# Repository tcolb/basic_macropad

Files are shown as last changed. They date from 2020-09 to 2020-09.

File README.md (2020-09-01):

# basic_macropad
 
A small macropad with programmable keys, hot-swap MX connectors, LEDS, 3D printed case, and volume encoder

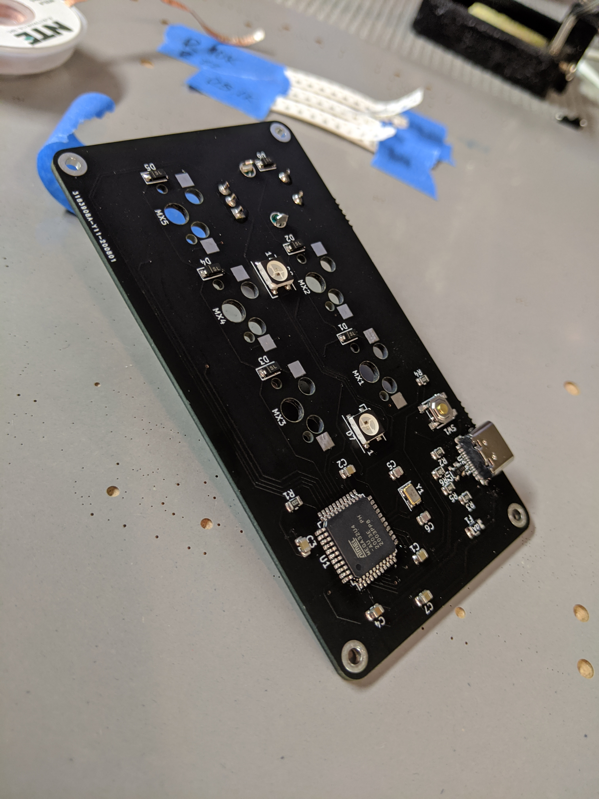
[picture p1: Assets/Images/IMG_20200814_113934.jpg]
PCB

CASE

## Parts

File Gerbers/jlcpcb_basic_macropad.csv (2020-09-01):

Comment | Designator | Footprint | LCSC
0.1uF | C1,C2,C3 | Capacitor_SMD:C_0805_2012Metric | C49678
10uF | C4 | Capacitor_SMD:C_0805_2012Metric | C15850
22pF | C5,C6 | Capacitor_SMD:C_0805_2012Metric | C1804
1uF | C7 | Capacitor_SMD:C_0805_2012Metric | C28323
SOD-123 | D1,D2,D3,D4,D5,D6 | Diode_SMD:D_SOD-123 | C8598
WS2812B | D7,D8 | LED_SMD:LED_WS2812B_PLCC4_5.0x5.0mm_P3.2mm | C114586
500mA | F1 | Fuse:Fuse_1206_3216Metric | C206993
MountingHole_Pad | H1,H2,H3,H4 | MountingHole:MountingHole_2.2mm_M2_Pad
MX-NoLED | MX1,MX2,MX3,MX4,MX5 | MX_Only:MXOnly-1U-Hotswap
10k | R1,R4 | Resistor_SMD:R_0805_2012Metric | C17414
5.1k | R2,R3 | Resistor_SMD:R_0805_2012Metric | C27834
22 | R5,R6 | Resistor_SMD:R_0805_2012Metric | C17561
SW_Push | SW1 | random-keyboard-parts:SKQG-1155865 | C318884
Rotary_Encoder_Switch | SW2 | Rotary_Encoder:RotaryEncoder_Alps_EC11E-Switch_Vertical_H20mm_CircularMountingHoles
ATmega32U4-AU | U1 | Package_QFP:TQFP-44_10x10mm_P0.8mm | C44854
PRTR5V0U2X | U2 | random-keyboard-parts:SOT143B
HRO-TYPE-C-31-M-12 | USB1 | Type-C:HRO-TYPE-C-31-M-12-Assembly
16MHz | Y1 | Crystal:Crystal_SMD_3225-4Pin_3.2x2.5mm | C13738

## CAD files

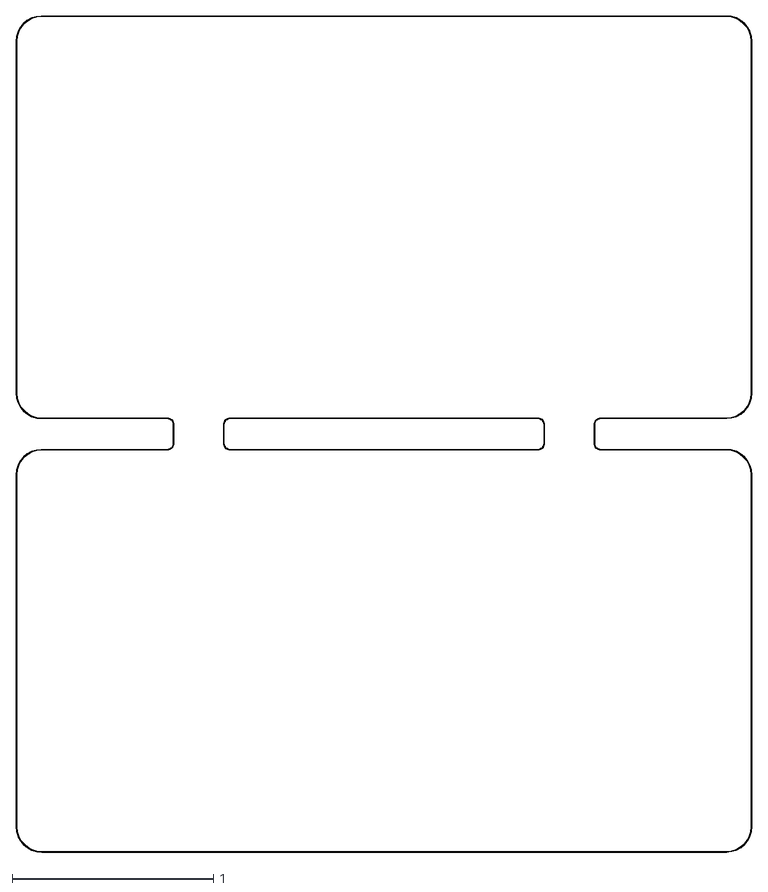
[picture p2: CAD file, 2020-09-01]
Assets/basic_macropad-Edge_Cuts.dxf
3.66 x 4.16

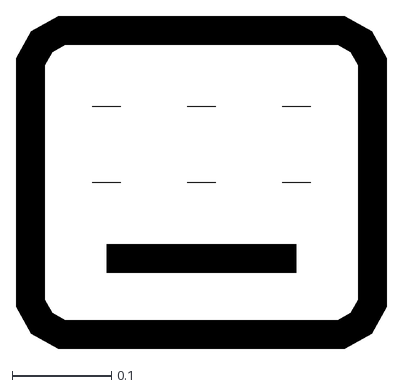
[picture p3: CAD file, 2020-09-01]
Assets/keyboard.dxf
0.372 x 0.334

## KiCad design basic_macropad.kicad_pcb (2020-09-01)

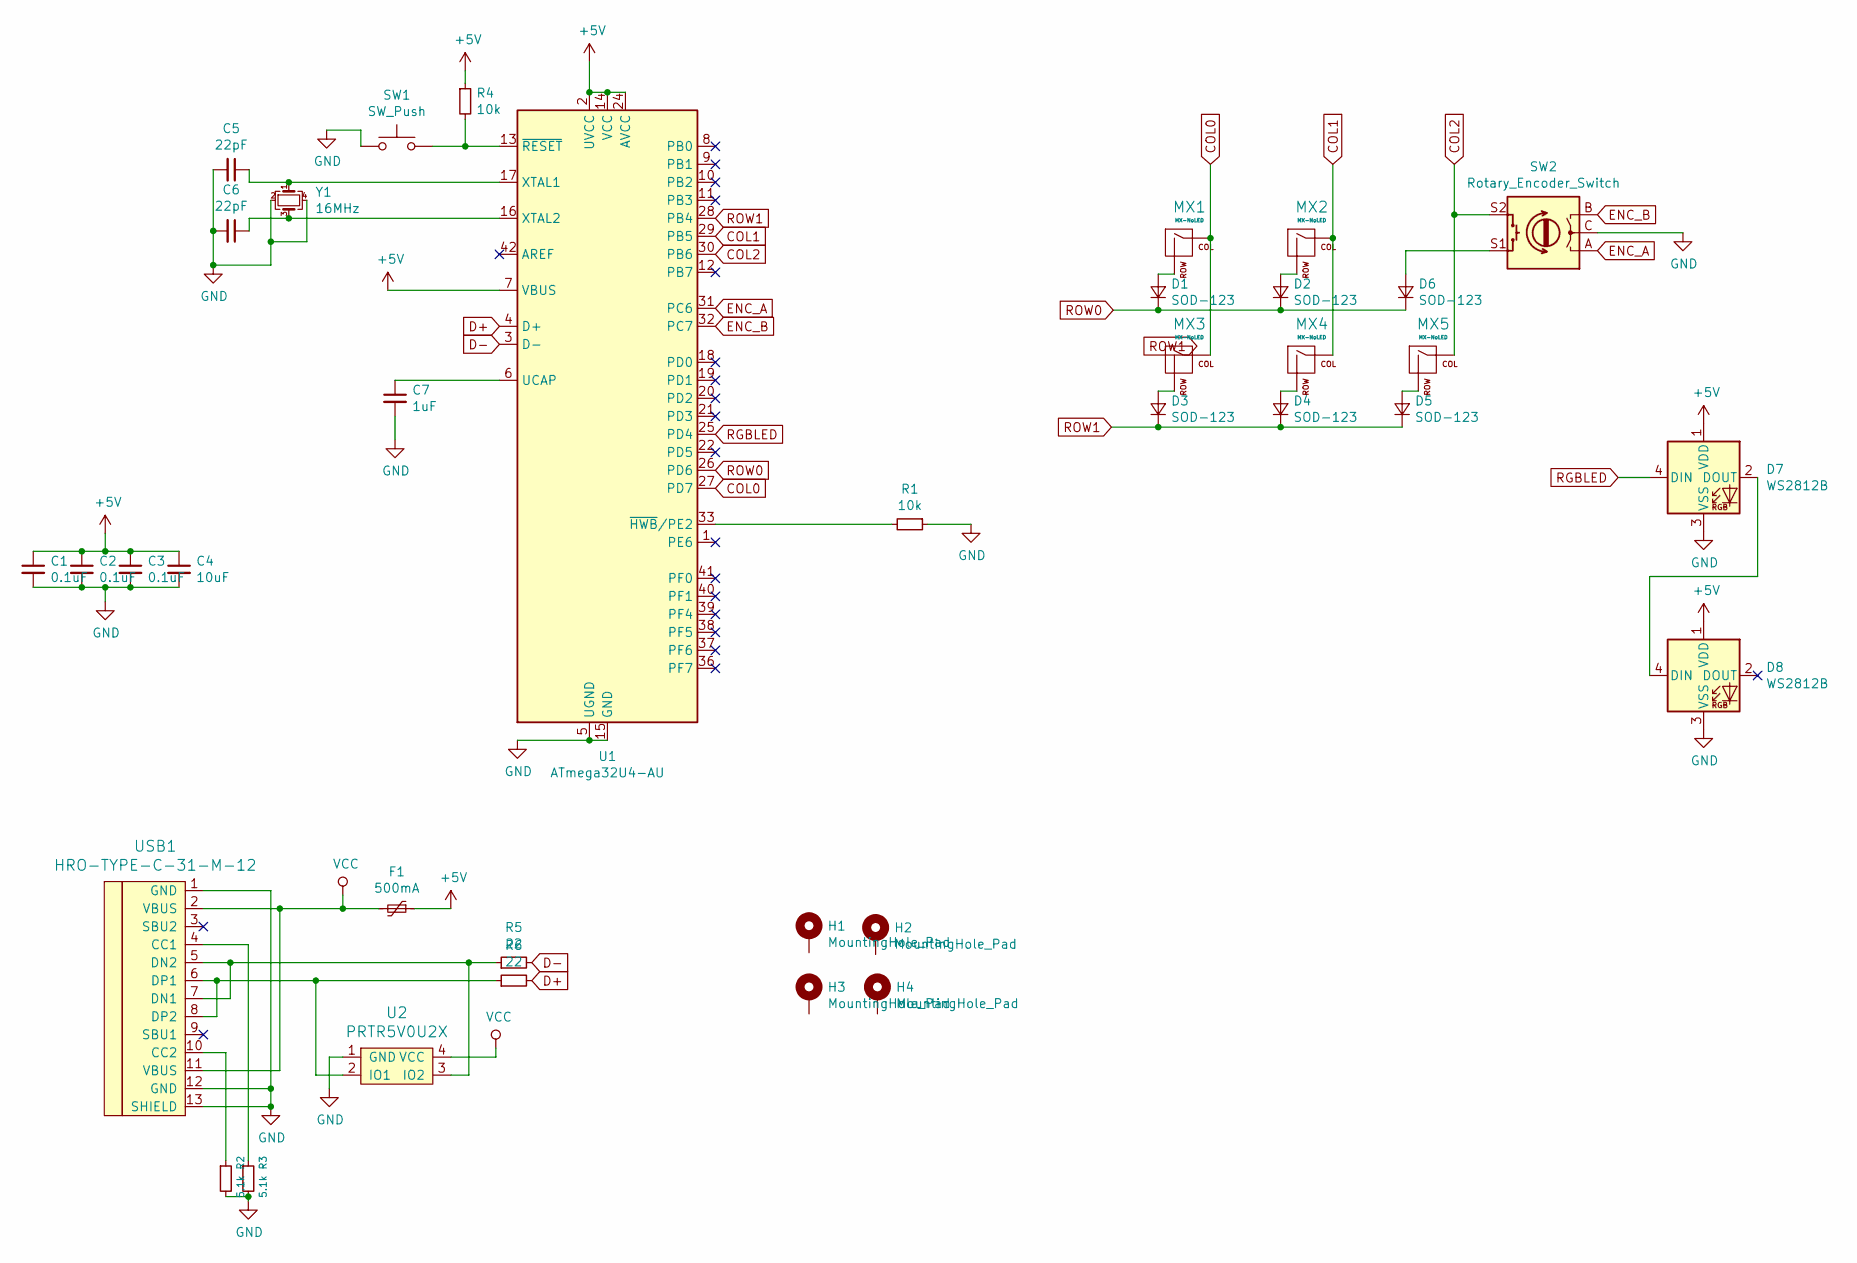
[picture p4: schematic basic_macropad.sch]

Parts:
C1, C2, C3: 0.1uF; C_0805_2012Metric; LCSC C49678
C4: 10uF; C_0805_2012Metric; LCSC C15850
C5, C6: 22pF; C_0805_2012Metric; LCSC C1804
C7: 1uF; C_0805_2012Metric; LCSC C28323
D1, D2, D3, D4, D5, D6: SOD-123; D_SOD-123; LCSC C8598
D7, D8: WS2812B; LED_WS2812B_PLCC4_5.0x5.0mm_P3.2mm; LCSC C114586
F1: 500mA; Fuse_1206_3216Metric; LCSC C206993
H1, H2, H3, H4: MountingHole_Pad; MountingHole_2.2mm_M2_Pad
MX1, MX2, MX3, MX4, MX5: MX-NoLED; MXOnly-1U-Hotswap
R1, R4: 10k; R_0805_2012Metric; LCSC C17414
R2, R3: 5.1k; R_0805_2012Metric; LCSC C27834
R5, R6: 22; R_0805_2012Metric; LCSC C17561
SW1: SW_Push; SKQG-1155865; LCSC C318884
SW2: Rotary_Encoder_Switch; RotaryEncoder_Alps_EC11E-Switch_Vertical_H20mm_CircularMoun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
U1: ATmega32U4-AU; TQFP-44_10x10mm_P0.8mm; LCSC C44854
U2: PRTR5V0U2X; SOT143B
USB1: HRO-TYPE-C-31-M-12; HRO-TYPE-C-31-M-12-Assembly
Y1: 16MHz; Crystal_SMD_3225-4Pin_3.2x2.5mm; LCSC C13738

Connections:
+5V: C1.1, C2.1, C3.1, C4.1, D7.1 (VDD), D8.1 (VDD), F1.1, R4.1, U1.2 (UVCC), U1.7 (VBUS), U1.14 (VCC), U1.24 (AVCC), U1.34 (VCC), U1.44 (AVCC)
COL0: MX1.1 (COL), MX3.1 (COL), U1.27 (PD7)
COL1: MX2.1 (COL), MX4.1 (COL), U1.29 (PB5)
COL2: MX5.1 (COL), SW2.S2, U1.30 (PB6)
D+: R6.2, U1.4 (D+)
D-: R5.2, U1.3 (D-)
ENC_A: SW2.A, U1.31 (PC6)
ENC_B: SW2.B, U1.32 (PC7)
GND: C1.2, C2.2, C3.2, C4.2, C5.2, C6.2, C7.2, D7.3 (VSS), D8.3 (VSS), R1.1, R2.2, R3.2, SW1.1, SW2.C, U1.5 (UGND), U1.15 (GND), U1.23 (GND), U1.35 (GND), U1.43 (GND), U2.1 (GND), USB1.1 (GND), USB1.12 (GND), USB1.13 (SHIELD), Y1.2, Y1.4
unnamed: C5.1, U1.17 (XTAL1), Y1.1
unnamed: C6.1, U1.16 (XTAL2), Y1.3
unnamed: C7.1, U1.6 (UCAP)
unnamed: D1.2 (A), MX1.2 (ROW)
unnamed: D2.2 (A), MX2.2 (ROW)
unnamed: D3.2 (A), MX3.2 (ROW)
unnamed: D4.2 (A), MX4.2 (ROW)
unnamed: D5.2 (A), MX5.2 (ROW)
unnamed: D6.2 (A), SW2.S1
unnamed: D7.2 (DOUT), D8.4 (DIN)
unnamed: R1.2, U1.33 (~HWB~/PE2)
unnamed: R2.1, USB1.10 (CC2)
unnamed: R3.1, USB1.4 (CC1)
unnamed: R4.2, SW1.2, U1.13 (~RESET)
unnamed: R5.1, U2.3 (IO2), USB1.5 (DN2), USB1.7 (DN1)
unnamed: R6.1, U2.2 (IO1), USB1.6 (DP1), USB1.8 (DP2)
RGBLED: D7.4 (DIN), U1.25 (PD4)
ROW0: D1.1 (K), D2.1 (K), D6.1 (K), U1.26 (PD6)
ROW1: D3.1 (K), D4.1 (K), D5.1 (K), U1.28 (PB4)
VCC: F1.2, U2.4 (VCC), USB1.2 (VBUS), USB1.11 (VBUS)

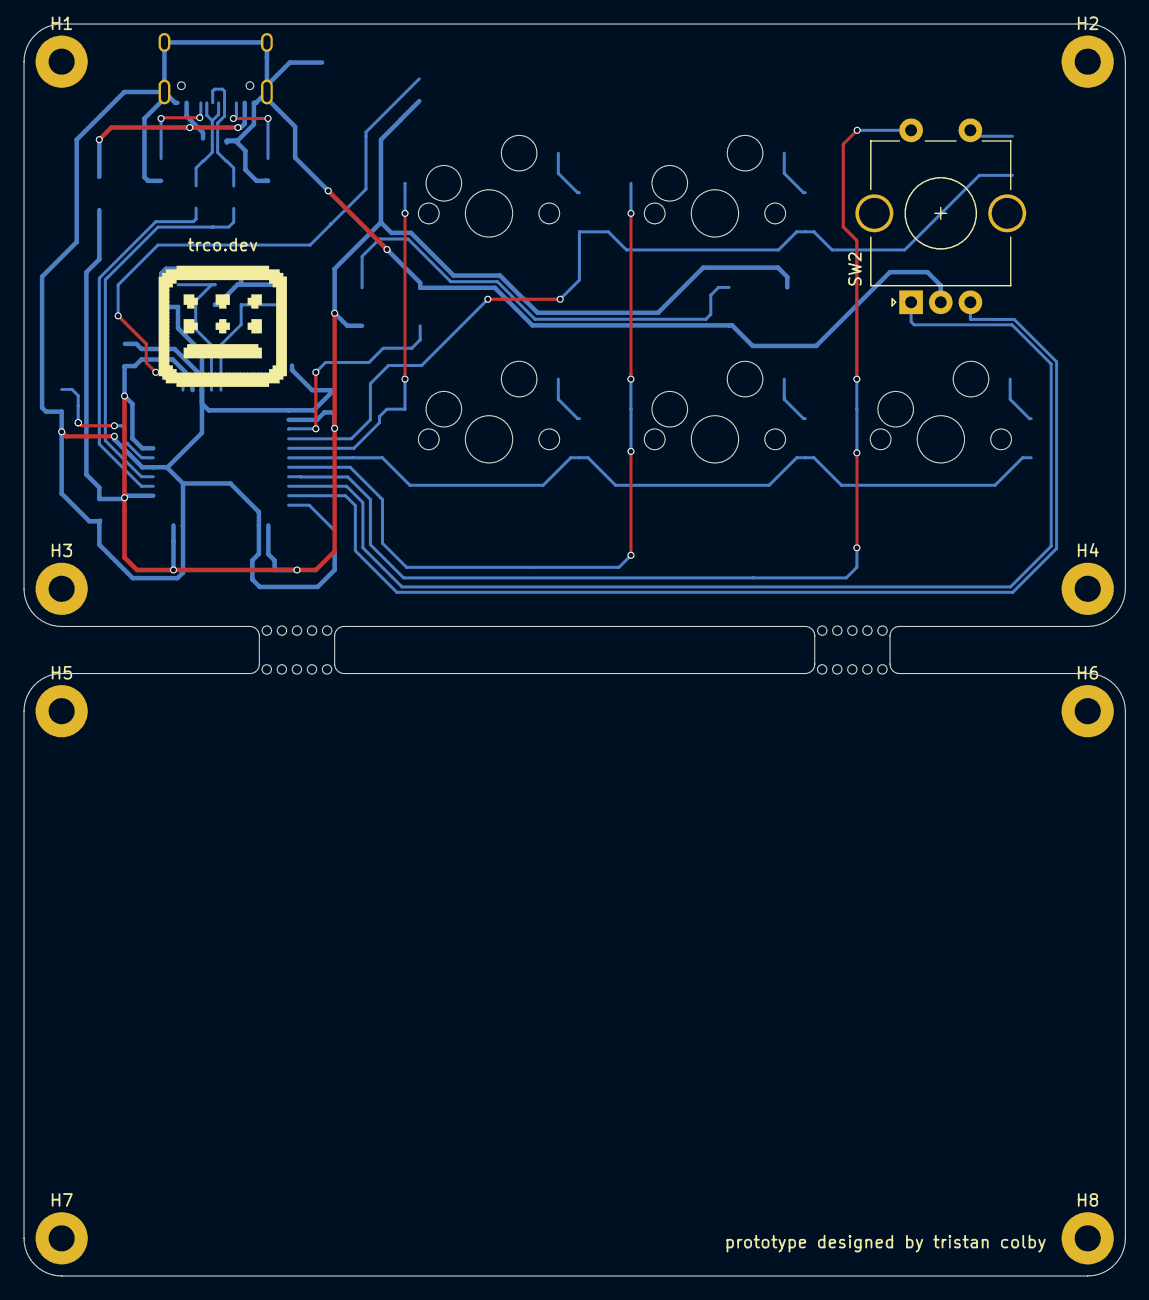
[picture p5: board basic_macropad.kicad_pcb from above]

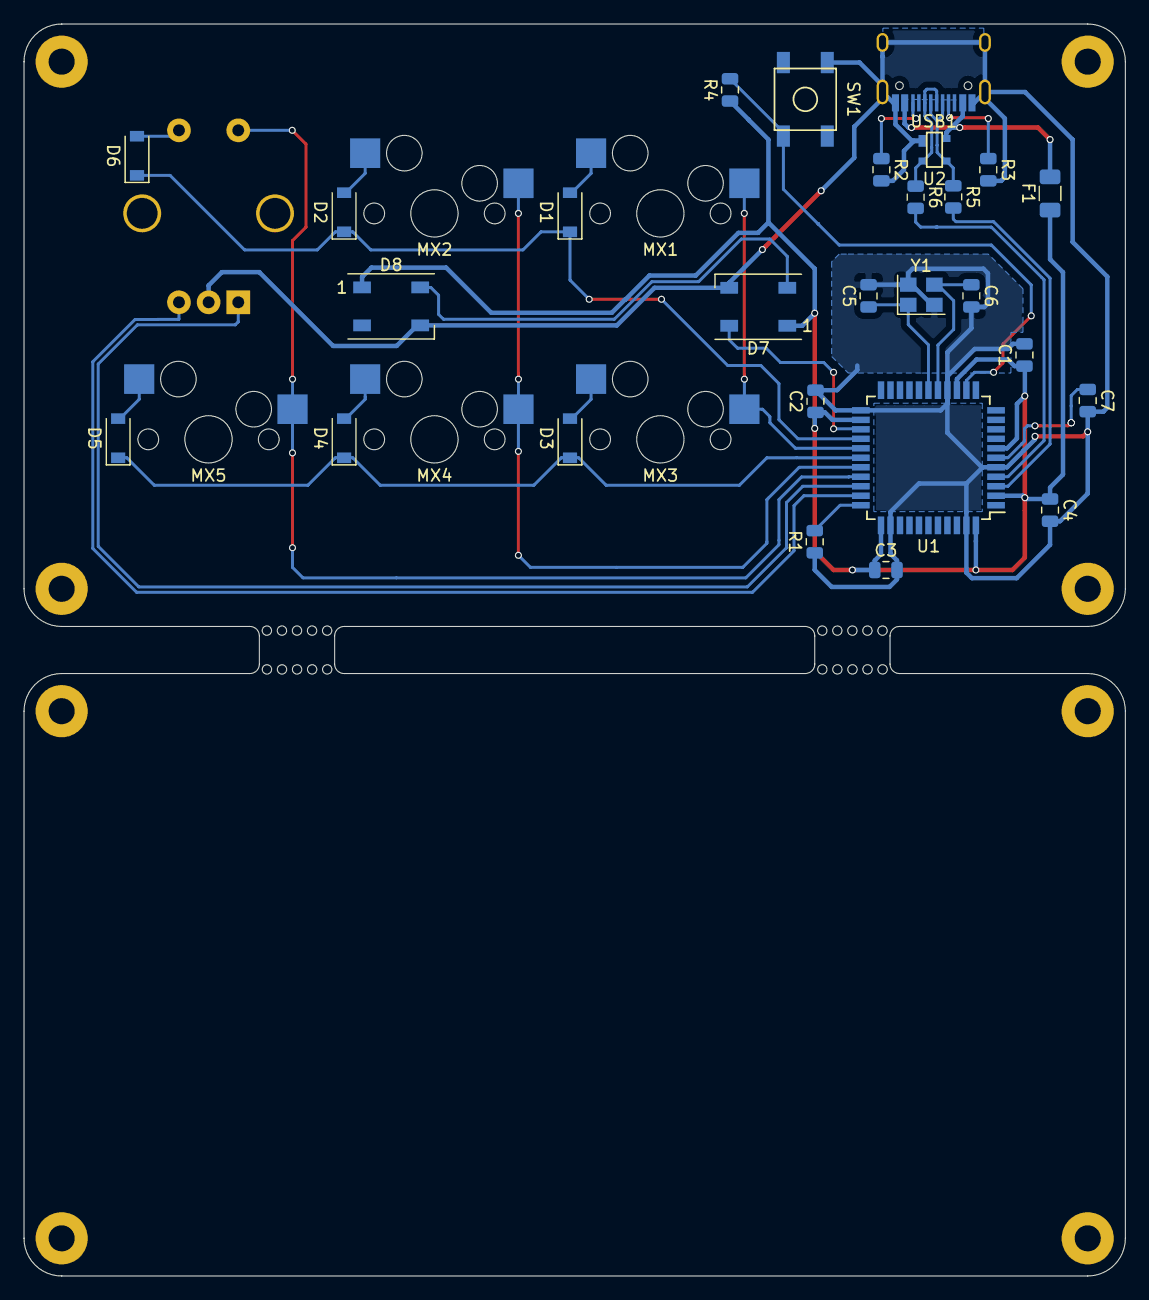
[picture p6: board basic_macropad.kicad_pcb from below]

Board: 2 copper layers, 92.9 x 105.6 mm, 42 parts (27 on the bottom side), 29 nets.

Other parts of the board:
H5, H6, H7, H8: MountingHole_Pad; MountingHole_2.2mm_M2_Pad
LOGO: LOGO_Smallest

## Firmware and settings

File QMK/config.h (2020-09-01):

/*
Copyright 2012 Jun Wako <wakojun@gmail.com>

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
You should have received a copy of the GNU General Public License
along with this program.  If not, see <http://www.gnu.org/licenses/>.
*/

#pragma once

#include "config_common.h"

/* USB Device descriptor parameter */
#define VENDOR_ID       0xBEEF
#define PRODUCT_ID      0xDEAD
#define RAW_USAGE_PAGE  0xFF60
#define RAW_USAGE_ID    0x61
#define DEVICE_VER      0x0002
#define MANUFACTURER    trco
#define PRODUCT         trco6
#define DESCRIPTION     5 key + encoder board

/* key matrix size */
#define MATRIX_ROWS 2
#define MATRIX_COLS 3
#define DIODE_DIRECTION COL2ROW

/*
 * Keyboard Matrix Assignments
 *
 * Change this to how you wired your keyboard
 * COLS: AVR pins used for columns, left to right
 * ROWS: AVR pins used for rows, top to bottom
 * DIODE_DIRECTION: COL2ROW = COL = Anode (+), ROW = Cathode (-, marked on diode)
 *                  ROW2COL = ROW = Anode (+), COL = Cathode (-, marked on diode)
 *                  NO_DIODE = switches are directly connected to AVR pins
 *
*/
#define MATRIX_ROW_PINS { D6, B4 }
#define MATRIX_COL_PINS { D7, B5, B6 }

// encoder
#define ENCODERS_PAD_A { C6 }
#define ENCODERS_PAD_B { C7 }
#define ENCODER_RESOLUTION 2

// ws2812 RGB LED
#define RGB_DI_PIN D4
#define RGBLED_NUM 2    // Number of LEDs
#define RGBLIGHT_ANIMATIONS

#define DEBOUNCE 5

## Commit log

2020-07-27 Adding kicad project
    [basic_macropad.kicad_pcb, basic_macropad.sch]
2020-07-27 Added footprint libraries
2020-07-30 Almost done
    [basic_macropad.sch]

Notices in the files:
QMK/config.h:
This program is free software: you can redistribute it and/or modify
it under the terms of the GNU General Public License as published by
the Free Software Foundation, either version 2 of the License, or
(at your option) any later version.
